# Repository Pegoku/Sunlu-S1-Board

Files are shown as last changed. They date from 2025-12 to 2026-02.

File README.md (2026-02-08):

# Sunlu S1 Filament Dryer Controller

Drop-in replacement controller board for the Sunlu S1 filament dryer. Features an STM32C011F4P6 microcontroller, 1.8" ST7735 TFT display, dual NTC temperature sensing, and precise PWM heater control; all optimized to fit in just 16 KB of flash. 

## Table of Contents
- [Overview](#overview)
- [Features](#features)
- [Quick Start](#quick-start)
- [User Guide](#user-guide)
- [Hardware](#hardware)
- [Technical Specs](#technical-specs)
- [Development](#development)
- [License](#license)

## Overview

Complete replacement for the stock Sunlu S1 control board, maintaining compatibility with the original heating element, chamber, and power connections. Adds a color TFT display in landscape mode and two-button navigation for precise temperature and time control (30–70°C configurable range, exceeding the stock 35–55°C limit).

The firmware uses integer-only math, dirty-check rendering, and batched SPI transfers to fit in the STM32C011's tiny 16 KB flash with room to spare.

### Gallery

Final build



<details>
<Summary>PCB</Summary>




</details>

## Features

### Display & Control
- **1.8" ST7735 TFT**: 160×128 px landscape, 16-bit RGB565 color
- **Two-button interface**: short-press (select/increment), long-press (toggle/cancel)
- **Three screens**: Main Status, Set Temperature, Set Time
- **Smart rendering**: dirty-check updates (only changed fields), instant button response

### Temperature & Heater Regulation
- **Dual NTC thermistors**: air temp (displayed) + heater element (safety)
- **Proportional PWM control** (~488 Hz): ramps heater power based on error from target
- **Dual safety cutoffs**: absolute (85°C) and dynamic (target + 5°C margin)
- **Integer-only lookup**: 11-point table with linear interpolation, no floating-point library
- **Fan control**: full speed during drying and overheat emergency

### Firmware Design
- **~600 lines**: single-loop, no RTOS/filesystem
- **~13 KB flash / ~2 KB RAM**: 80% flash usage, 33% RAM usage
- **Batched SPI**: 128-byte buffer (~100× faster than byte-by-byte)
- **Minimal font**: 5×7 bitmap, 29 glyphs only
- **No soft-float**: integer NTC lookup saves ~4 KB

## Quick Start

### Build
Requires `arm-none-eabi-gcc`, `cmake`, and `cube-cmake` installed.

```sh
cd Code
cmake --preset Debug
cmake --build build/Debug --target Code
```

### Flash
Using `st-flash`:

```sh
st-flash write build/Debug/Code.bin 0x08000000
```

Or use the VS Code task "Build and Flash" if configured.

## User Guide

### Main Screen (Status & Control)
- **Top**: Air temperature, Countdown timer (HH:MM)
- **Middle**: Current state (IDLE/RUN/PAUSE), target temperature setting
- **Bottom**: Action hints: BTN1=set, BTN2=start/pause/resume, hold BTN2=stop/reset

<details>
<summary>Example Main Screen</summary>



</details>

### Set Temperature Screen
- **Value**: Current target in °C
- **Controls**: 
  - **Short BTN1**: increment (or decrement if toggled)
  - **Long BTN1**: toggle UP/DOWN mode, hints show current direction
  - **Short BTN2**: confirm & advance to Set Time
  - **Long BTN2**: cancel & return to Main

<details>
<summary>Example Set Temp Screen</summary>


</details>

### Set Time Screen
- **Value**: Target drying time in HH:MM format
- **Controls**: Same as Set Temp (BTN1 for ±, long BTN1 to toggle, BTN2 to confirm/cancel)

<details>
<summary>Example Set Time Screen</summary>


</details>

### Operation
1. Press BTN1 on Main Screen → Set Temperature
2. Adjust with BTN1 (short = increment, long = toggle direction, watch hints)
3. Press BTN2 → Set Time
4. Adjust similarly, then press BTN2 → firmware returns to Main and **starts drying**
5. Monitor progress on Main Screen; press BTN2 to pause/resume
6. Hold BTN2 to stop and reset (returns to IDLE)

## Hardware

### Pinout & Connections
| Function | Pin | Module | Notes |
|---|-----|---|---|
| Display CS | PB7 | SPI1 | ST7735 chip select |
| Display DC | PA3 | SPI1 | Data/Command |
| Display RES | PC14 | GPIO | Reset |
| Display BL | PA8 | GPIO | Backlight (always ON) |
| Display SPI | PA5, PA6, PA7 | SPI1 | CLK, MISO, MOSI |
| Button 1 | PA4 | GPIO | Up/Set (active LOW, pull-up) |
| Button 2 | PA5 | GPIO | Select/Confirm (active LOW, pull-up) |
| Heater PWM | PA0 | TIM1_CH1 | 16-bit PWM (0–65535 = 0–100%) |
| Fan PWM | PA1 | TIM17_CH1 | 16-bit PWM (0–65535 = 0–100%) |
| Air NTC | PA11 | ADC_CH11 | 100k thermistor, 3.3 V divider |
| Heater NTC | PA12 | ADC_CH12 | 100k thermistor, 3.3 V divider |
| LED | PA2 | GPIO | Status indicator (on during RUN/PAUSE) |

See [Code/Core/Inc/main.h](Code/Core/Inc/main.h) for full pin configuration.

## Technical Specs

### MCU & Peripherals
- **MCU**: STM32C011F4P6 (Cortex-M0+, 32 MHz, 16 KB flash, 6 KB RAM)
- **Display**: ST7735 1.8" TFT, 160×128 px, 16-bit RGB565, SPI @ 16 MHz
- **PWM**: TIM1 (heater) + TIM17 (fan), ~488 Hz, 16-bit resolution
- **ADC**: 12-bit, dual-channel NTC reading @ 500 ms

### Temperature & Timing
- **Range**: 30–70°C (configurable `TMIN`/`TMAX`)
- **NTC**: 100 K, B=3950, ~1°C resolution
- **Button poll**: 20 ms (30 ms debounce, 1 s long-press)
- **Display refresh**: 250 ms idle on Main screen, instant on changes
- **Countdown**: 1 s ticks

### Power
- **Input**: 24 V DC
- **Heater**: ≤48 W (PWM-controlled)
- **Fan**: ≤2 W (PWM-controlled)
- **MCU + Display**: ≤100 mA @ 3.3 V
## Development

### Structure
```
├── CMakeLists.txt              # Build config
├── Core/
│   ├── Inc/
│   │   ├── main.h              # Pin definitions, HAL config
│   │   ├── dryer.h             # Public firmware API
│   │   └── ...
│   └── Src/
│       ├── main.c              # Entry point, HAL init
│       ├── dryer.c             # Firmware (600 lines): display driver, UI, control
│       └── ...
├── Drivers/
│   ├── CMSIS/
│   ├── STM32C0xx_HAL_Driver/   # ST HAL
│   └── ...
└── cmake/                       # Toolchain files
```

### Modifying the Firmware
- Temperature limits: edit `TMIN`, `TMAX`, `TDEF` in [Code/Core/Src/dryer.c](Code/Core/Src/dryer.c)
- Time limits: edit `MMIN`, `MMAX`, `MDEF`
- Safety margin: change `stmp + 5` in `Regulate()` function
- NTC calibration: update `ntc[]` lookup table in [Code/Core/Src/dryer.c](Code/Core/Src/dryer.c)

## Bill of Materials

See [BOM.csv](BOM.csv) for the complete component list and part numbers.

## License

This work is licensed under a
[Creative Commons Attribution-NonCommercial 4.0 International License][cc-by-nc].

[][cc-by-nc]

[cc-by-nc]: https://creativecommons.org/licenses/by-nc/4.0/
[cc-by-nc-image]: https://licensebuttons.net/l/by-nc/4.0/88x31.png
[cc-by-nc-shield]: https://img.shields.io/badge/License-CC%20BY--NC%204.0-lightgrey.svg

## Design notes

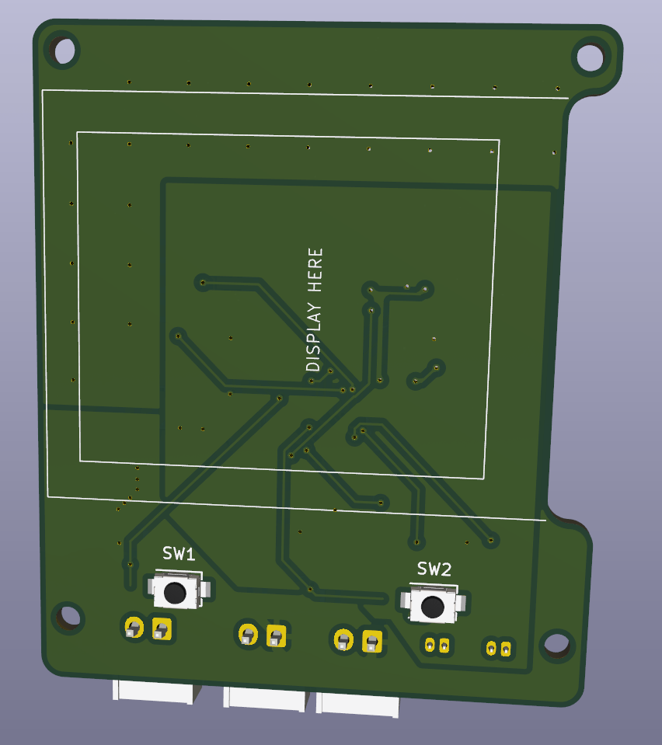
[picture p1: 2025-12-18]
image.png

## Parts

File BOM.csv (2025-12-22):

Index | LCSC# | MPN | Manufacturer | Package | Customer # | Description | RoHS | Quantity | MOQ | Multiple | Unit Price($) | Extended Price($) | Product Link
1 | C22388559 | ZX-MX1.25-2PWZ-R | Megastar | Through Hole,Right Angle,P=1.25mm |  | Connector Header 2 position 1.25mm Pitch 1A Right Angle -25℃~+85℃ | yes | 1 | 20 | 20 | 0.0172 | 0.34 | https://www.lcsc.com/product-detail/C22388559.html
2 | C7430463 | ZX-MX1.25-2PWZ | Megastar | Through Hole,Right Angle,P=1.25mm |  | Connector Header 2 position 1.25mm Pitch 1A Right Angle -25℃~+85℃ | yes | 1 | 50 | 50 | 0.0128 | 0.64 | https://www.lcsc.com/product-detail/C7430463.html
3 | C47326862 | A254F2W1-2H2P12 | JXTCONN | Through Hole,Right Angle,P=2.5mm |  | Connector Header 2 position 2.5mm Pitch 3A Right Angle -25℃~+85℃ | yes | 1 | 20 | 20 | 0.009 | 0.18 | https://www.lcsc.com/product-detail/C47326862.html
4 | C47326881 | A254F2W1-2R2P12 | JXTCONN | Through Hole,Right Angle,P=2.5mm |  | Connector Header 2 position 2.5mm Pitch 3A Right Angle -25℃~+85℃ | yes | 1 | 20 | 20 | 0.009 | 0.18 | https://www.lcsc.com/product-detail/C47326881.html
5 | C42422442 | AXH-2AW-11 | JXTCONN | Through Hole,Right Angle,P=2.54mm |  | Connector Header 2 position 2.5mm Pitch 2A Right Angle -25℃~+85℃ | yes | 1 | 50 | 50 | 0.0035 | 0.18 | https://www.lcsc.com/product-detail/C42422442.html
6 | C42163081 | HC-PZ254-11L-2x3PS | Hong Cheng | SMD,P=2.54mm |  | 2x3P 6P Gold Brass -40℃~+105℃ Pin Header Black 2.54mm 2.5mm 6mm 3A 2 2.54mm SMD,P=2.54mm Headers, Male Pins RoHS | yes | 1 | 10 | 10 | 0.0408 | 0.41 | https://www.lcsc.com/product-detail/C42163081.html
7 | C14663 | CC0603KRX7R9BB104 | YAGEO | 603 |  | 100nF ±10% 50V Ceramic Capacitor X7R 0603 | yes | 9 | 100 | 100 | 0.0025 | 0.25 | https://www.lcsc.com/product-detail/C14663.html
8 | C28323 | CL21B105KBFNNNE | Samsung Electro-Mechanics | 805 |  | 1uF ±10% 50V Ceramic Capacitor X7R 0805 | yes | 3 | 20 | 20 | 0.0092 | 0.18 | https://www.lcsc.com/product-detail/C28323.html
9 | C602037 | CL21A226MAYNNNE | Samsung Electro-Mechanics | 805 |  | 22uF ±20% 25V Ceramic Capacitor X5R 0805 | yes | 2 | 10 | 10 | 0.0219 | 0.22 | https://www.lcsc.com/product-detail/C602037.html
10 | C138687 | CL32B106KBJNNNE | Samsung Electro-Mechanics | 1210 |  | 10uF ±10% 50V Ceramic Capacitor X7R 1210 | yes | 1 | 1 | 1 | 0.1585 | 0.16 | https://www.lcsc.com/product-detail/C138687.html
11 | C100042 | CC0603KRX7R9BB103 | YAGEO | 603 |  | 10nF ±10% 50V Ceramic Capacitor X7R 0603 | yes | 1 | 100 | 100 | 0.0022 | 0.22 | https://www.lcsc.com/product-detail/C100042.html
12 | C1621 | CL10B472KB8NNNC | Samsung Electro-Mechanics | 603 |  | 4.7nF ±10% 50V Ceramic Capacitor X7R 0603 | yes | 1 | 50 | 50 | 0.0047 | 0.24 | https://www.lcsc.com/product-detail/C1621.html
13 | C178639 | EEHZA1V470P | PANASONIC | SMD,D6.3xL5.8mm |  | 47uF 35V Aluminum - Polymer Capacitors 10000hrs@105℃ Surface Mount D6.3xL5.8mm | yes | 1 | 5 | 5 | 0.3383 | 1.69 | https://www.lcsc.com/product-detail/C178639.html
14 | C965799 | XL-1608SURC-06 | XINGLIGHT | 603 |  | Red 625nm LED Indication - Discrete 2.3V 0603 | yes | 1 | 100 | 100 | 0.003 | 0.3 | https://www.lcsc.com/product-detail/C965799.html
15 | C150066 | NSI45030AT1G | onsemi | SOD-123 |  | PWM 30mA 1 SOD-123 Current Regulation/Management RoHS | yes | 1 | 5 | 5 | 0.102 | 0.51 | https://www.lcsc.com/product-detail/C150066.html
16 | C91546 | B360B-13-F | DIODES | SMB(DO-214AA) |  | 100A 60V 700mV@3A 3A SMB(DO-214AA) Single Diodes RoHS | yes | 1 | 5 | 5 | 0.0972 | 0.49 | https://www.lcsc.com/product-detail/C91546.html
17 | C41367223 | BSMD1206C-1200T | BHFUSE | 1206 |  | 2A 72V Fuse Surface Mount 1206 | yes | 1 | 10 | 10 | 0.0491 | 0.49 | https://www.lcsc.com/product-detail/C41367223.html
18 | C6808085 | ANR4020T100M | APV | SMD,4x4mm |  | 10uH Magnetic Shielded Inductor 1.7A SMD,4x4mm Fixed Inductors RoHS | yes | 1 | 10 | 10 | 0.0375 | 0.38 | https://www.lcsc.com/product-detail/C6808085.html
19 | C727349 | SIA440DJ-T1-GE3 | VISHAY | PowerPAK-SC-70-6L |  | N-Channel 40V 8.6A 3.5W Surface Mount PowerPAK-SC-70-6L | yes | 1 | 1 | 1 | 0.3317 | 0.66 | https://www.lcsc.com/product-detail/C727349.html
20 | C20917 | AO3400A | AOS | SOT-23-3L |  | N-Channel 30V Surface Mount SOT-23-3L | yes | 2 | 5 | 5 | 0.0735 | 0.37 | https://www.lcsc.com/product-detail/C20917.html
21 | C720477 | TS-1088-AR02016 | XUNPU | SMD,4x3mm |  | Tactile Switch SPST 160gf 2mm SMD (SMT) Tab 4mm x 3mm Surface Mount | yes | 2 | 10 | 10 | 0.0421 | 0.42 | https://www.lcsc.com/product-detail/C720477.html
22 | C7373263 | STM32C011F4P6TR | ST | TSSOP-20 |  | ARM Cortex-M0+ 48MHz 18 TSSOP-20 Microcontrollers RoHS | yes | 2 | 1 | 1 | 0.4756 | 5.71 | https://www.lcsc.com/product-detail/C7373263.html
23 | C53213 | TPS54240DGQR | TI | MSOP-10-EP |  | 2.5MHz Buck Adjustable 1 MSOP-10-EP Voltage Regulators - DC DC Switching Regulators RoHS | yes | 2 | 1 | 1 | 0.4821 | 0.96 | https://www.lcsc.com/product-detail/C53213.html
24 | C105588 | RC0603FR-07100RL | YAGEO | 603 |  | 100mW 100Ω 75V ±100ppm/℃ Thick Film Resistor ±1% 0603 Chip Resistor - Surface Mount RoHS | yes | 5 | 100 | 100 | 0.0011 | 0.11 | https://www.lcsc.com/product-detail/C105588.html
25 | C98220 | RC0603FR-0710KL | YAGEO | 603 |  | 100mW 10kΩ 75V ±100ppm/℃ Thick Film Resistor ±1% 0603 Chip Resistor - Surface Mount RoHS | yes | 2 | 100 | 100 | 0.0011 | 0.11 | https://www.lcsc.com/product-detail/C98220.html
26 | C23345 | 0603WAF220JT5E | UNI-ROYAL | 603 |  | 22Ω ±1% 100mW 0603 Thick Film Resistor | yes | 1 | 100 | 100 | 0.001 | 0.1 | https://www.lcsc.com/product-detail/C23345.html
27 | C2933196 | FRC0603F3162TS | FOJAN | 603 |  | 31.6kΩ ±1% 100mW 0603 Thick Film Resistor | yes | 1 | 100 | 100 | 0.001 | 0.1 | https://www.lcsc.com/product-detail/C2933196.html
28 | C22788 | 0603WAF1243T5E | UNI-ROYAL | 603 |  | 124kΩ ±1% 100mW 0603 Thick Film Resistor | yes | 1 | 100 | 100 | 0.0011 | 0.22 | https://www.lcsc.com/product-detail/C22788.html
29 | C2907011 | FRC0603F2002TS | FOJAN | 603 |  | 20kΩ ±1% 100mW 0603 Thick Film Resistor | yes | 1 | 100 | 100 | 0.0009 | 0.09 | https://www.lcsc.com/product-detail/C2907011.html
30 | C14675 | RC0603FR-07100KL | YAGEO | 603 |  | 100mW 100kΩ 75V ±100ppm/℃ Thick Film Resistor ±1% 0603 Chip Resistor - Surface Mount RoHS | yes | 5 | 100 | 100 | 0.001 | 0.1 | https://www.lcsc.com/product-detail/C14675.html
31 | C23179 | 0603WAF4700T5E | UNI-ROYAL | 603 |  | 470Ω ±1% 100mW 0603 Thick Film Resistor | yes | 1 | 100 | 100 | 0.0012 | 0.12 | https://www.lcsc.com/product-detail/C23179.html
32 | C137745 | RC0603FR-0730K1L | YAGEO | 603 |  | 100mW 30.1kΩ 75V ±100ppm/℃ Thick Film Resistor ±1% 0603 Chip Resistor - Surface Mount RoHS | yes | 1 | 100 | 100 | 0.0012 | 0.12 | https://www.lcsc.com/product-detail/C137745.html
33 | C2933219 | FRC0603F4123TS | FOJAN | 603 |  | 412kΩ ±1% 100mW 0603 Thick Film Resistor | yes | 1 | 100 | 100 | 0.001 | 0.1 | https://www.lcsc.com/product-detail/C2933219.html
34 |  |  | LCSC |  |  | Shipping |  | 1 |  |  | 8.41 | 8.41
53 |  |  | JLCPCB |  |  | PCB |  | 1 |  |  | 5 | 5
36 |  |  | JLCPCB |  |  | Shipping |  | 1 |  |  | 20.32 | 20.32
37 |  |  | Aliexpress |  |  | Display |  | 1 |  |  | 5.51 | 5.51

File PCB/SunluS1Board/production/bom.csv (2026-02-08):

Designator | Footprint | Quantity | Value | LCSC Part #
C1, C11, C12, C14, C17, C2, C3, C5, C9 | 0603 | 9 | 100nF
C10, C13, C4 | 0805 | 3 | 1uF
C18, C19 | 0805 | 2 | 22uF
C20 | 1210 | 1 | 10uF
C21 | 0603 | 1 | 10nF
C22 | 0603 | 1 | 4.7nF
C6 | CAP-SMD_BD6.3-L6.6-W6.6-FD | 1 | 47uF
D1 | 0603 | 1 | LED
D2 | D_SOD-123 | 1 | NSI45030AT1G
D3 | D_SMB | 1 | B360
D4, D5 | D_SMA | 2 | SS34
F1 | 1206 | 1 | Fuse
J1 | STP0177A-128160 | 1 | Conn_01x14
J2 | Molex_PicoBlade_53048-0210_1x02_P1.25mm_Horizontal | 1 | aNTC
J3 | Molex_PicoBlade_53048-0210_1x02_P1.25mm_Horizontal | 1 | hNTC
J4 | CONN-TH_2P-P2.54_AXH-2AW-11 | 1 | Fan
J5 | CONN-TH_2P-P2.54_AXH-2AW-11 | 1 | HT
J6 | CONN-TH_2P-P2.54_AXH-2AW-11 | 1 | Power
J7 | PinHeader_2x03_P2.54mm_Vertical_SMD | 1 | Conn_02x03_Odd_Even
L1 | L_APV_ANR4020 | 1 | 10uH
Q1 | SC-70-6L_L2.0-W2.0-P0.65-BL | 1 | SIA440DJ-T1-GE3 | C727349
Q2, Q3 | SOT-23 | 2 | AO3400A
R1, R10, R11, R2, R6 | 0603 | 5 | 100
R12, R15 | 0603 | 2 | 10k
R13 | 0603 | 1 | 22
R14 | 0603 | 1 | 31.6k
R16 | 0603 | 1 | 124k
R17 | 0603 | 1 | 30.1k
R18 | 0603 | 1 | 412k
R19 | 0603 | 1 | 20k
R3, R5, R7, R8, R9 | 0603 | 5 | 100k
R4 | 0603 | 1 | 470
SW1, SW2 | SW-SMD_L3.9-W3.0-P4.45 | 2 | CS1213AGF260
U1 | TSSOP-20_4.4x6.5mm_P0.65mm | 1 | STM32C011F4Px
U3 | HVSSOP-10-1EP_3x3mm_P0.5mm_EP1.83x1.89mm_ThermalVias | 1 | TPS54240DGQ

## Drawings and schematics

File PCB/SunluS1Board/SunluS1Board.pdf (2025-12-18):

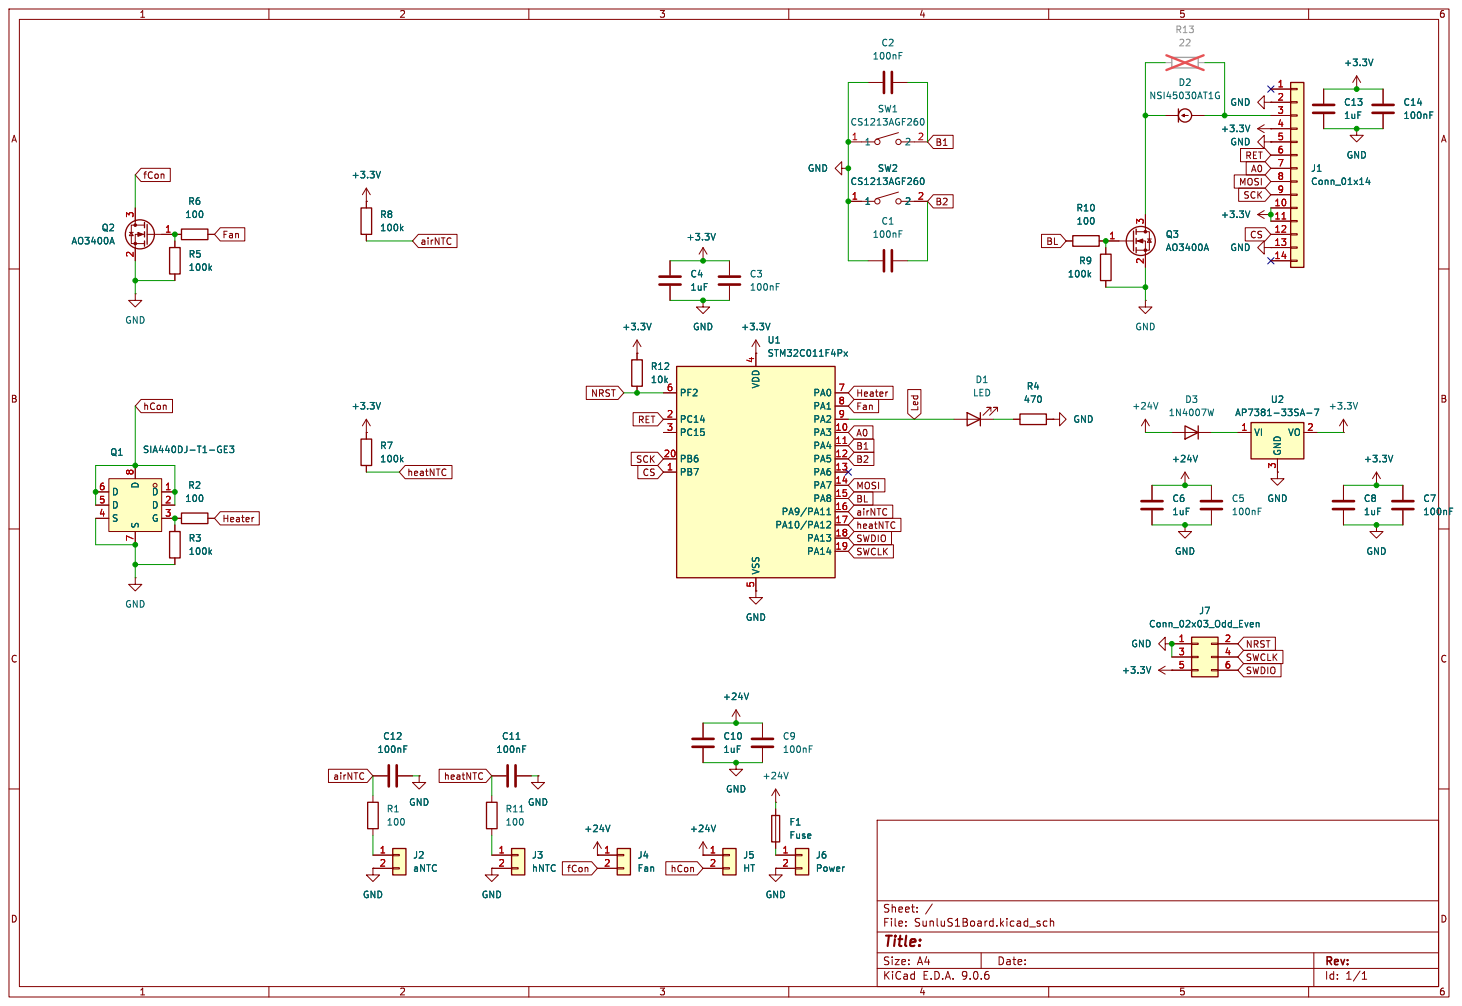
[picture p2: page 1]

Id: 1/1 Title: File: SunluS1Board.kicad_sch Sheet: /

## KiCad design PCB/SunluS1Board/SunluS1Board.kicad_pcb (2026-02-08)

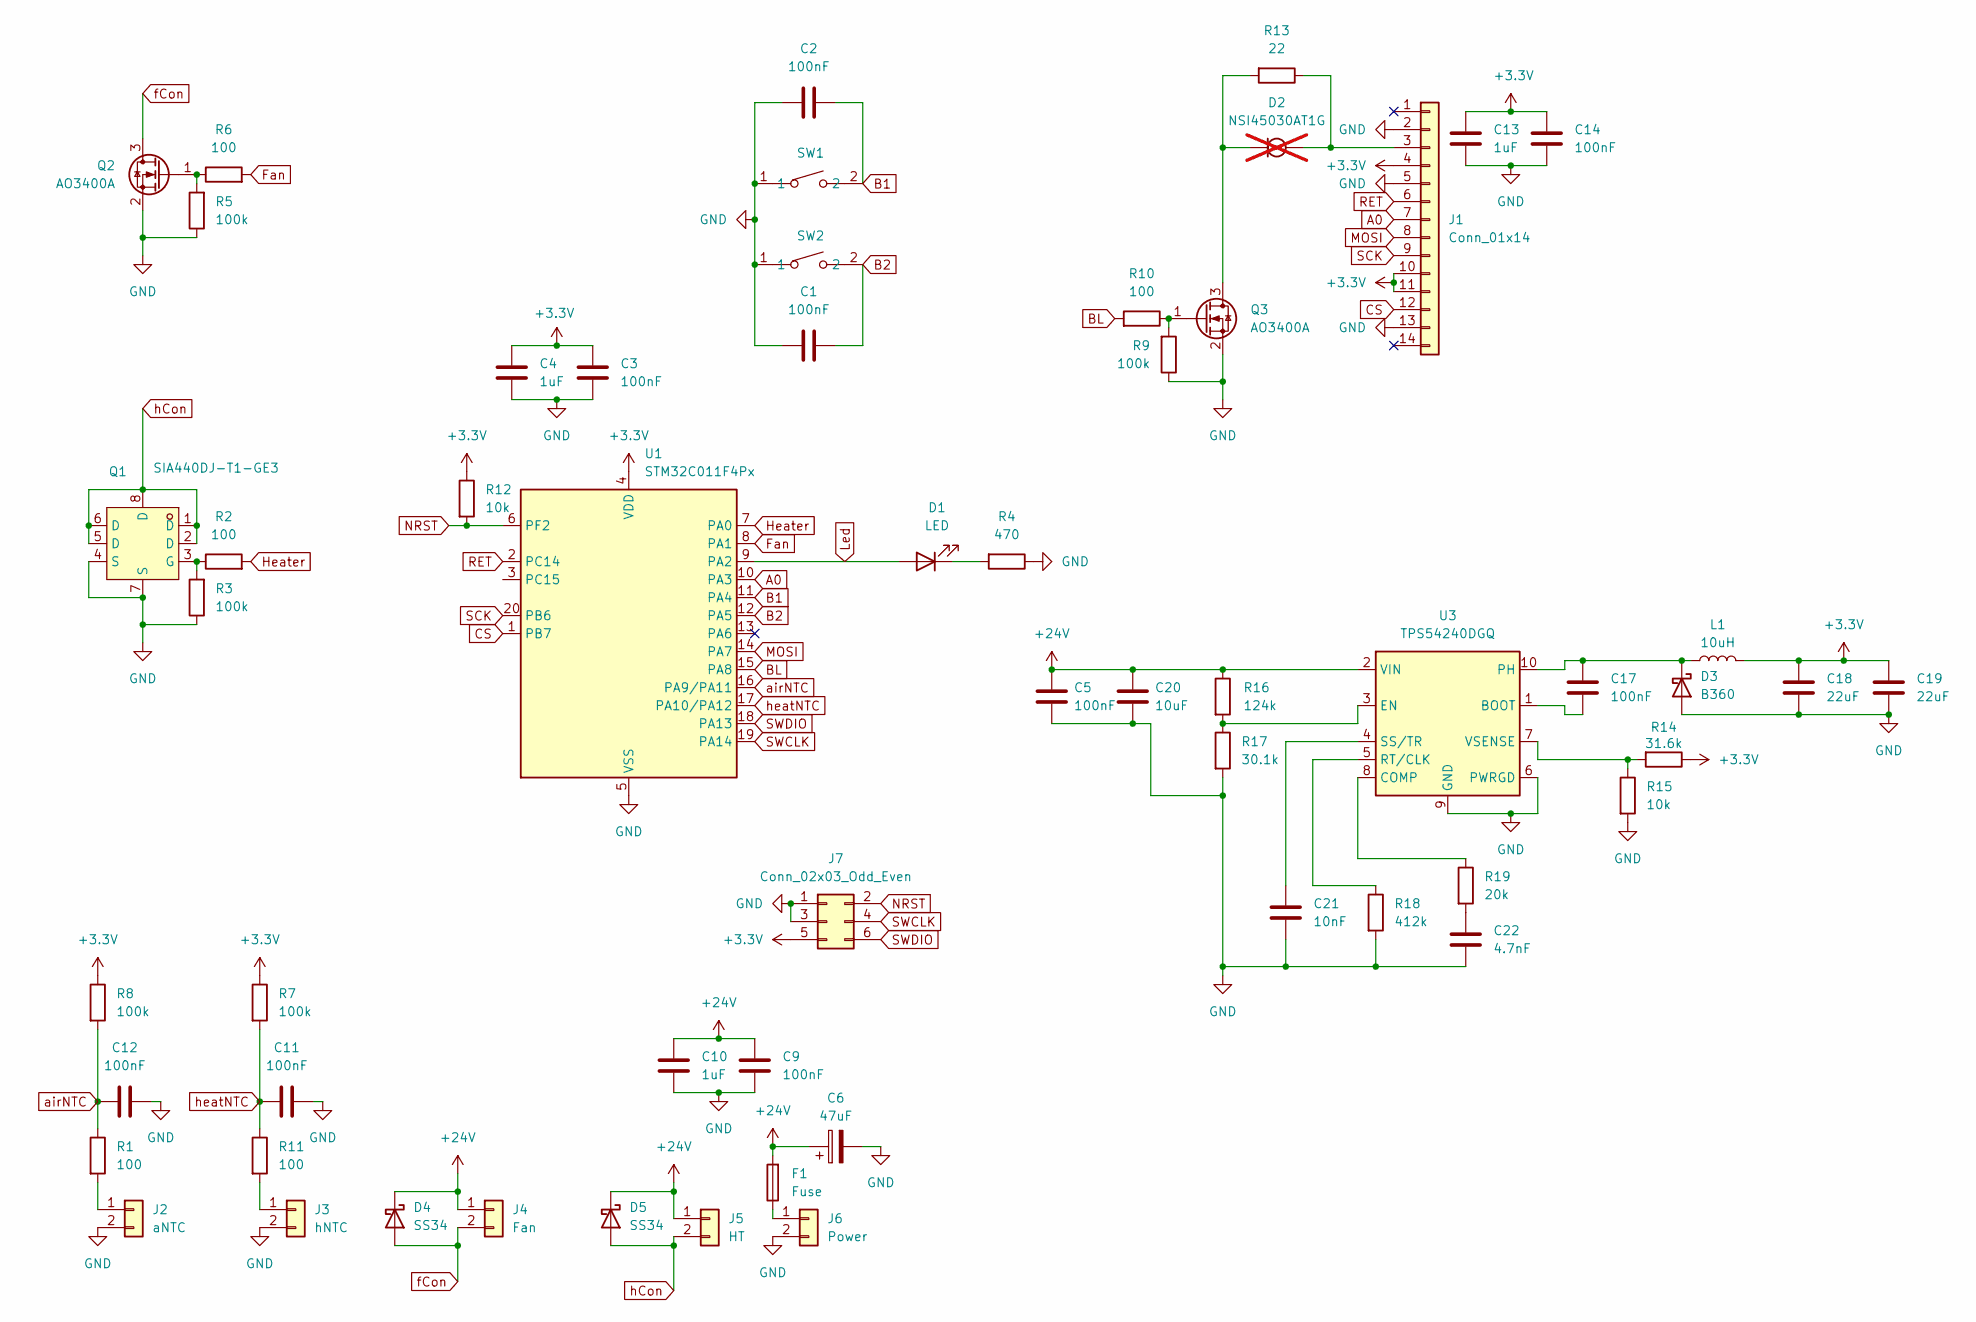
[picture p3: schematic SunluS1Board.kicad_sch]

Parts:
C1, C2, C3, C5, C9, C11, C12, C14, C17: 100nF; C_0603_1608Metric
C4, C10, C13: 1uF; C_0805_2012Metric
C6: 47uF; CAP-SMD_BD6.3-L6.6-W6.6-FD
C18, C19: 22uF; C_0805_2012Metric
C20: 10uF; C_1210_3225Metric
C21: 10nF; C_0603_1608Metric
C22: 4.7nF; C_0603_1608Metric
D1: LED; LED_0603_1608Metric
D2: NSI45030AT1G; D_SOD-123; not fitted
D3: B360; D_SMB
D4, D5: SS34; D_SMA
F1: Fuse; Fuse_1206_3216Metric
J1: Conn_01x14; STP0177A-128160
J2: aNTC; Molex_PicoBlade_53048-0210_1x02_P1.25mm_Horizontal
J3: hNTC; Molex_PicoBlade_53048-0210_1x02_P1.25mm_Horizontal
J4: Fan; CONN-TH_2P-P2.54_AXH-2AW-11
J5: HT; CONN-TH_2P-P2.54_AXH-2AW-11
J6: Power; CONN-TH_2P-P2.54_AXH-2AW-11
J7: Conn_02x03_Odd_Even; PinHeader_2x03_P2.54mm_Vertical_SMD
L1: 10uH; L_APV_ANR4020
Q1: SIA440DJ-T1-GE3; SC-70-6L_L2.0-W2.0-P0.65-BL; LCSC Part C727349
Q2, Q3: AO3400A; SOT-23
R1, R2, R6, R10, R11: 100; R_0603_1608Metric
R3, R5, R7, R8, R9: 100k; R_0603_1608Metric
R4: 470; R_0603_1608Metric
R12, R15: 10k; R_0603_1608Metric
R13: 22; R_0603_1608Metric
R14: 31.6k; R_0603_1608Metric
R16: 124k; R_0603_1608Metric
R17: 30.1k; R_0603_1608Metric
R18: 412k; R_0603_1608Metric
R19: 20k; R_0603_1608Metric
SW1, SW2: CS1213AGF260; SW-SMD_L3.9-W3.0-P4.45
U1: STM32C011F4Px; TSSOP-20_4.4x6.5mm_P0.65mm
U3: TPS54240DGQ; HVSSOP-10-1EP_3x3mm_P0.5mm_EP1.83x1.89mm_ThermalVias

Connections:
+3.3V: C3.1, C4.1, C13.1, C14.1, C18.1, C19.1, J1.4, J1.10, J1.11, J7.5, L1.2, R7.1, R8.1, R12.1, R14.1, U1.4 (VDD)
+24V: C5.1, C6.1, C9.1, C10.1, C20.1, D4.1 (K), D5.1 (K), F1.2, J4.1, J5.1, R16.1, U3.2 (VIN)
A0: J1.7, U1.10 (PA3)
B1: C2.1, SW1.2, U1.11 (PA4)
B2: C1.1, SW2.2, U1.12 (PA5)
BL: R10.2, U1.15 (PA8)
CS: J1.12, U1.1 (PB7)
Fan: R6.2, U1.8 (PA1)
GND: C1.2, C2.2, C3.2, C4.2, C5.2, C6.2, C9.2, C10.2, C11.2, C12.2, C13.2, C14.2, C18.2, C19.2, C20.2, C21.2, C22.2, D3.2 (A), J1.2, J1.5, J1.13, J2.2, J3.2, J6.2, J7.1, J7.3, Q1.4 (S), Q1.7 (S), Q2.2 (S), Q3.2 (S), R3.1, R4.1, R5.1, R9.1, R15.2, R17.2, R18.2, SW1.1, SW2.1, U1.5 (VSS), U3.6 (PWRGD), U3.9 (GND), U3.11 (GND)
Heater: R2.2, U1.7 (PA0)
Led: D1.2 (A), U1.9 (PA2)
MOSI: J1.8, U1.14 (PA7)
NRST: J7.2, R12.2, U1.6 (PF2)
unnamed: C22.1, R19.2
unnamed: D1.1 (K), R4.2
unnamed: D2.2 (A), J1.3, R13.1
unnamed: D2.1 (K), Q3.3 (D), R13.2
unnamed: C17.1, D3.1 (K), L1.1, U3.10 (PH)
unnamed: J2.1, R1.2
unnamed: J3.1, R11.2
unnamed: F1.1, J6.1
unnamed: Q1.3 (G), R2.1, R3.2
unnamed: Q2.1 (G), R5.2, R6.1
unnamed: Q3.1 (G), R9.2, R10.1
unnamed: C17.2, U3.1 (BOOT)
unnamed: R19.1, U3.8 (COMP)
unnamed: R16.2, R17.1, U3.3 (EN)
unnamed: R18.1, U3.5 (RT/CLK)
unnamed: C21.1, U3.4 (SS/TR)
unnamed: R14.2, R15.1, U3.7 (VSENSE)
RET: J1.6, U1.2 (PC14)
SCK: J1.9, U1.20 (PB6)
SWCLK: J7.4, U1.19 (PA14)
SWDIO: J7.6, U1.18 (PA13)
airNTC: C12.1, R1.1, R8.2, U1.16 (PA9/PA11)
fCon: D4.2 (A), J4.2, Q2.3 (D)
hCon: D5.2 (A), J5.2, Q1.1 (D), Q1.2 (D), Q1.5 (D), Q1.6 (D), Q1.8 (D)
heatNTC: C11.1, R7.2, R11.1, U1.17 (PA10/PA12)

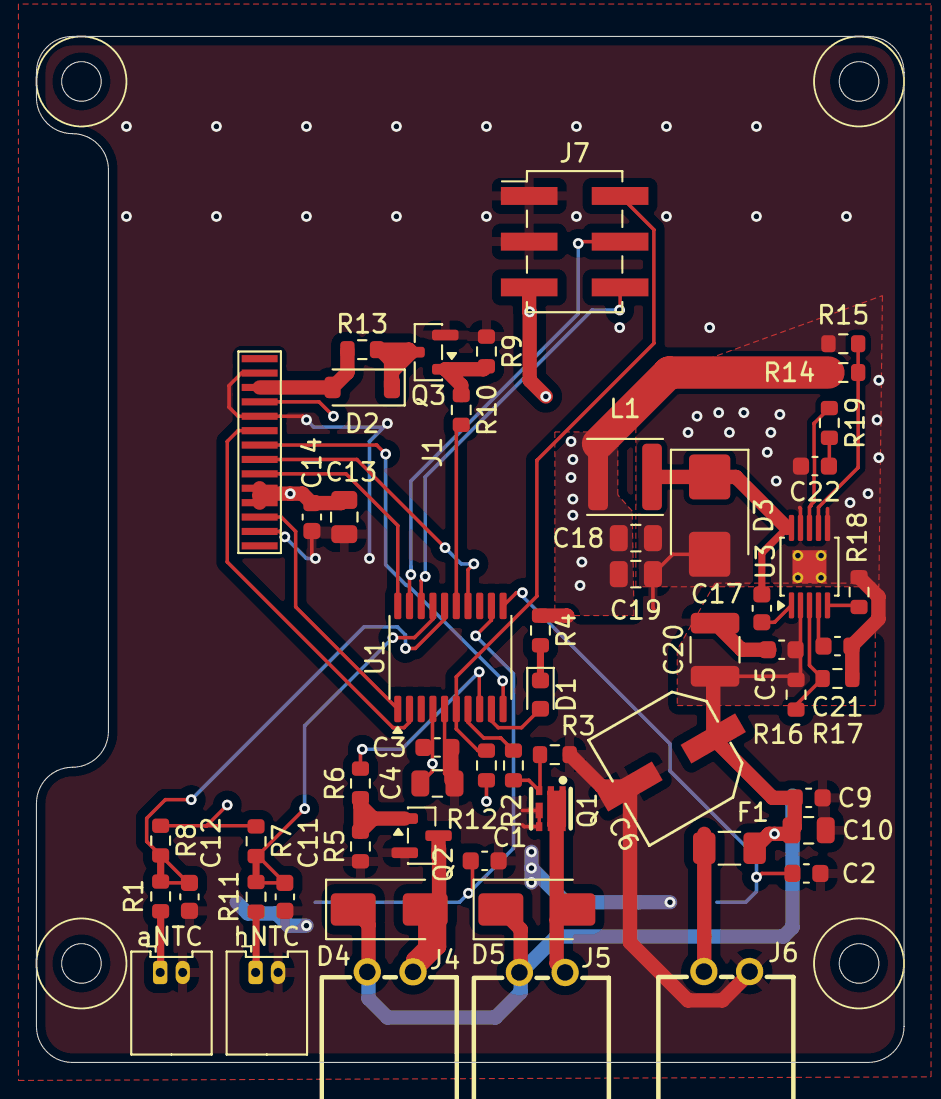
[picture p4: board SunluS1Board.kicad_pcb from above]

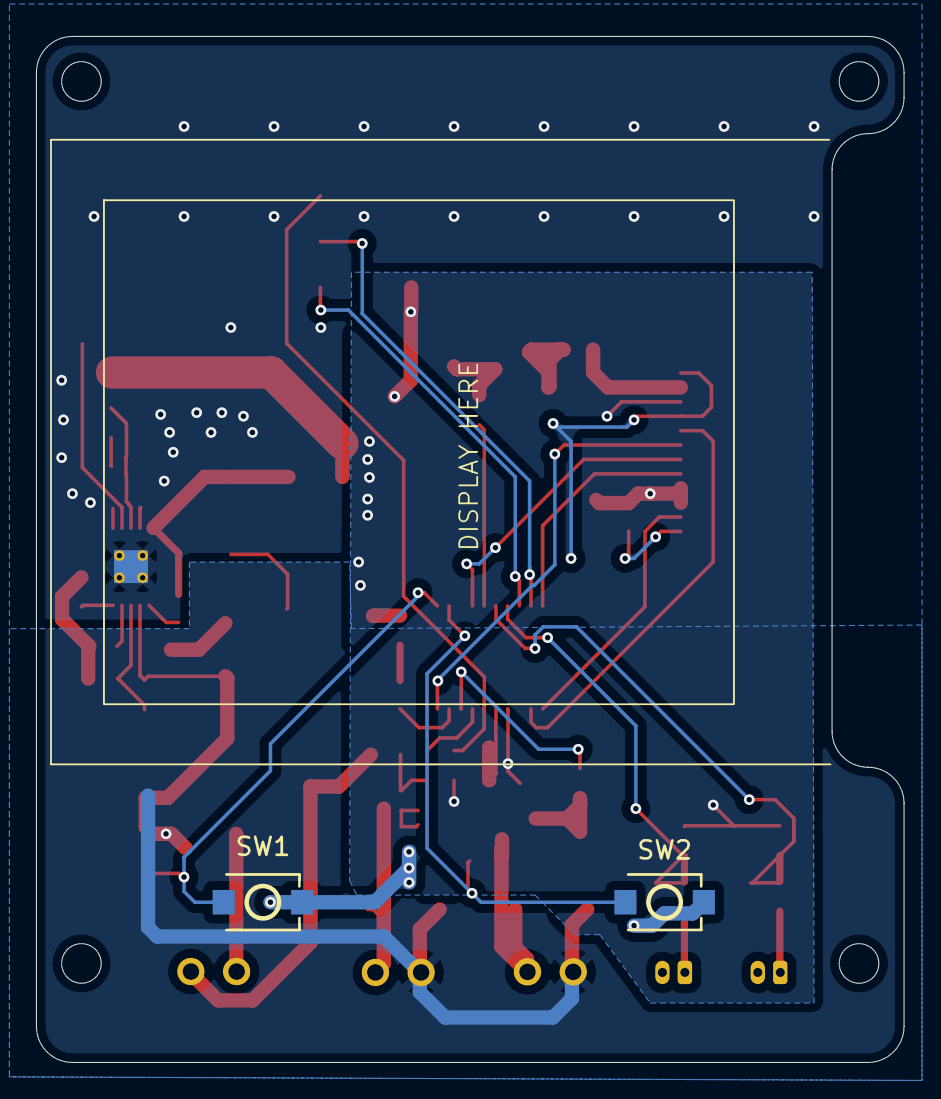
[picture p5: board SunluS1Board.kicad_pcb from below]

Board: 2 copper layers, 48.2 x 57.0 mm, 58 parts (2 on the bottom side), 38 nets.

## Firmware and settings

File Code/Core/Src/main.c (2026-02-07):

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
/* Includes ------------------------------------------------------------------*/
#include "main.h"
#include "stm32c0xx_hal_gpio.h"

/* USER CODE BEGIN Includes */
#include "dryer.h"
/* USER CODE END Includes */

ADC_HandleTypeDef hadc1;

SPI_HandleTypeDef hspi1;

TIM_HandleTypeDef htim1;
TIM_HandleTypeDef htim17;

void SystemClock_Config(void);
static void MX_GPIO_Init(void);
static void MX_ADC1_Init(void);
static void MX_TIM1_Init(void);
static void MX_TIM17_Init(void);
static void MX_SPI1_Init(void);
/**
  * @brief  The application entry point.
  * @retval int
  */
int main(void)
{

  /* MCU Configuration--------------------------------------------------------*/

  /* Reset of all peripherals, Initializes the Flash interface and the Systick. */
  HAL_Init();

  /* Configure the system clock */
  SystemClock_Config();

  /* Initialize all configured peripherals */
  MX_GPIO_Init();
  MX_ADC1_Init();
  MX_TIM1_Init();
  MX_TIM17_Init();
  MX_SPI1_Init();
  /* USER CODE BEGIN 2 */

  Dryer_Init();

  /* USER CODE END 2 */

  /* Infinite loop */
  /* USER CODE BEGIN WHILE */
  while (1)
  {
    /* USER CODE END WHILE */

    Dryer_Loop();

    /* USER CODE BEGIN 3 */
  }
  /* USER CODE END 3 */
}

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


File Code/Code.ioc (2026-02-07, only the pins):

Mcu.UserName=STM32C011F4Px
PA0.GPIO_Label=heater
PA0.Signal=S_TIM1_CH1
PA1.GPIO_Label=fan
PA1.Signal=S_TIM17_CH1
PA13.Signal=DEBUG_SWDIO
PA14-BOOT0.Signal=DEBUG_SWCLK
PA2.GPIO_Label=led
PA2.Signal=GPIO_Output
PA3.GPIO_Label=A0
PA3.Signal=GPIO_Output
PA4.GPIO_Label=b1
PA4.Signal=GPIO_Input
PA5.GPIO_Label=b2
PA5.Signal=GPIO_Input
PA7.Signal=SPI1_MOSI
PA8.GPIO_Label=BL
PA8.Signal=GPIO_Output
PB6.Signal=SPI1_SCK
PB7.GPIO_Label=CS
PB7.Signal=GPIO_Output

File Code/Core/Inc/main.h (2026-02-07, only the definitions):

#define CS_Pin GPIO_PIN_7
#define CS_GPIO_Port GPIOB
#define RES_Pin GPIO_PIN_14
#define RES_GPIO_Port GPIOC
#define heater_Pin GPIO_PIN_0
#define heater_GPIO_Port GPIOA
#define fan_Pin GPIO_PIN_1
#define fan_GPIO_Port GPIOA
#define led_Pin GPIO_PIN_2
#define led_GPIO_Port GPIOA
#define A0_Pin GPIO_PIN_3
#define A0_GPIO_Port GPIOA
#define b1_Pin GPIO_PIN_4
#define b1_GPIO_Port GPIOA
#define b2_Pin GPIO_PIN_5
#define b2_GPIO_Port GPIOA
#define BL_Pin GPIO_PIN_8
#define BL_GPIO_Port GPIOA
#define airNTC_Pin GPIO_PIN_11
#define airNTC_GPIO_Port GPIOA
#define heatNTC_Pin GPIO_PIN_12
#define heatNTC_GPIO_Port GPIOA
#define ST7735_CS_Pin GPIO_PIN_7
#define ST7735_CS_GPIO_Port GPIOB
#define ST7735_DC_Pin GPIO_PIN_3
#define ST7735_DC_GPIO_Port GPIOA
#define ST7735_RES_Pin RES_Pin
#define ST7735_RES_GPIO_Port RES_GPIO_Port
#define ST7735_BL_Pin BL_Pin
#define ST7735_BL_GPIO_Port BL_GPIO_Port

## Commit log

2025-12-08 use SPI instead of I2C
    [SunluS1Board.kicad_pcb, SunluS1Board.kicad_sch]
2025-12-08 start base schematic
    [SunluS1Board.kicad_sch]
2025-12-15 finish schematic
    [SunluS1Board.kicad_sch]
2025-12-15 add swd header
    [SunluS1Board.kicad_sch]
2025-12-15 refine schematic
    [SunluS1Board.kicad_sch]
2025-12-15 use half duplex for the spi
2025-12-15 more decaps
    [SunluS1Board.kicad_sch]
2025-12-15 custom footprint
    [SunluS1Board.kicad_sch]
2025-12-15 add current regulator to display
    [SunluS1Board.kicad_sch]
2025-12-15 add resistor fallback
    [SunluS1Board.kicad_sch]
2025-12-15 fix footprint
2025-12-17 finish schematic fr
    [SunluS1Board.kicad_sch]
2025-12-17 start pcb
    [SunluS1Board.kicad_pcb]
2025-12-17 continue PCB
    [SunluS1Board.kicad_pcb]
2025-12-17 update footprint
    [SunluS1Board.kicad_pcb, SunluS1Board.kicad_sch]
2025-12-17 placement done
    [SunluS1Board.kicad_pcb]
2025-12-17 mostly routed
    [SunluS1Board.kicad_pcb]
2025-12-18 continue routing
    [SunluS1Board.kicad_pcb]
2025-12-18 fillet pcb
2025-12-18 DRC and 3d models
    [SunluS1Board.kicad_pcb, SunluS1Board.kicad_sch]
2025-12-18 fix buttons
2025-12-21 fix schematic
    [SunluS1Board.kicad_sch]
2025-12-21 start buck design
2025-12-21 schematic: finish buck
    [SunluS1Board.kicad_sch]
2025-12-21 continue buck
    [SunluS1Board.kicad_pcb]
2025-12-22 start buck pcb
    [SunluS1Board.kicad_pcb]
2025-12-22 f*** I placed and routed the buck at the wrong layer...
    [SunluS1Board.kicad_pcb]
2025-12-22 mostly finsish pcb, again
    [SunluS1Board.kicad_pcb]
2025-12-22 finish V2
    [SunluS1Board.kicad_pcb, SunluS1Board.kicad_sch]
2025-12-22 finish pcb and BOM
    [BOM.csv, SunluS1Board.kicad_sch, bom.csv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]
2025-12-22 finish BOM
    [BOM.csv, bom.csv]
2025-12-22 add display
    [BOM.csv]
2026-02-05 stm32 stuff + blink!
2026-02-07 add direction control for temperature and time adjustments
2026-02-08 use htemp to regulate heater temperature
2026-02-08 Fixes for V2
    [SunluS1Board.kicad_pcb, SunluS1Board.kicad_sch, bom.csv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]

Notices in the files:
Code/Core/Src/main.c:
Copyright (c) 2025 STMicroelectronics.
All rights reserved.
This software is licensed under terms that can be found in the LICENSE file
